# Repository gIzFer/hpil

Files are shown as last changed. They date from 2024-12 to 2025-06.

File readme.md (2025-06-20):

# HP-IL bridge/translator to USB/Serial

## What does it do
So what does this do? The device simply takes what it receives from the HP-IL side and sends it over serial. Same in the other direction. sends 2 bytes, the `command` and the `data` terminated with a `'\n'` (ascii 10) character

## Why
I had a 3468A and wanted to control it from my computer and make the electronics circuit simple an easy and of parts everyone could have at hand. Difficulty was relayed onto the firmware, but even so was kept simple without implementing the state machines of the protocol.

## Materials needed
- Atmega328p
- 2 NPN and 4 PNP transistors. 2 PNP handle the input and the other 2 and 2 are for a push pull arrangement to send data. I sprinkled on them some diodes to speed them up.
- Ethernet transformer. Fastest pulses are around 1µs and an ethernet transformer seems to be able to handle that quite well. You can find them in every device having a rj45 port, old computers, routers, switches, etc.

[client docs](./client/readme.md)

## Added made up codes

### 1XX

They are for extra messages you can send to the device, like asking it to just send the message it just received

#### 1XX List of codes
- 101: send back the last message received
- 102: get calibration data
- 103: get firmware version

### 2XX

They are for extra messages you can receive from the device  like errors

#### 2XX List of codes
- 201: received message buffer overflowed, answers with 201 and the last byte it received

# todo:
- read pins instead of delays (NOPs) when talking to be able to read answer at the same time im writing
- add images to readme
- add "console mode" so no need for the python client, to be able to directly send the commands to it

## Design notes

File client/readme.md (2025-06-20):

# HP3468A client

Example on how to interact with the firmware. I made it to mainly use it with the HP3468A. No idea of how it will interact with any other HP-IL device.

----
##### Contents
- [How to use](#How-to-use)
- [Code "docs"](#Code-"docs)
 - [setDisplay](#setDisplay)
 - [setDigits](#setDigits)
 - [setTriggerMode](#setTriggerMode)
 - [setAutoZero](#setAutoZero)
 - [setFunction](#setFunction)
 - [readSingleValue](#readSingleValue)
 - [getStatus](#getStatus)
 - [printStatus](#printStatus)
 - [getCal](#getCal)
 - [printCal](#printCal)
 - [triggerReading](#triggerReading)

 ----
## How to use

`multimeter = HP3468A(args.usb_id)`
in my case I get it at /dev/ttyUSBn, so i.e. I call `./main.py --usb_id 0` to run the example

uhh... Not very multiOS compatible... change accordingly to your OS... :P
`self.ser = serial.Serial("/dev/ttyUSB" + str(usb_id), 115200, timeout=1)`

## Code "docs"

### setDisplay

**desc**: changes display mode to either normal or to show text

**method**: `setDisplay(displayMode_, text="")`

**params**:

-   `displayMode_`: enum `displayModes.normal` or `displayModes.text`
-   `text`: empty by default. automatically truncated if length exceeds available space on display

_always write text in uppercase characters otherwise cursed things might show_

_(they "stored other characters in the lowercase characters space")_

### setDigits

**desc**: changes meter digits. Precision and sampling speed change accordingly

**method**: `setDigits(digits)`

**params**:

-   `digits`: valid values are 3, 4 and 5

### setTriggerMode

**desc**: trigger internally or single trigger

**method**: `setTriggerMode(triggerMode_)`

**params**:

-   `triggerMode_`:  enum `triggerModes.internal` or `triggerModes.single`

### setAutoZero

**desc**: Enable or disable autozero, enabled by default. (Nulls internal offset errors)

**method**: `setAutoZero(value)`

**params**:

-   `value`:  True or False

### setFunction

**desc**: Configure function and its range

**method**: `setFunction(function_, range=0)`

**params**:

-   `function_`: enum `functions`
-   `range`: numerical value.

Since range depends on option parameters values are combined here:

-   `functions.DC_voltage`: 0 (Autorange), 1 (.3V), 2 (3V), 3 (30V), 4 (300V)
-   `functions.AC_voltage`: 0 (Autorange), 1 (.3V), 2 (3V), 3 (30V), 4 (300V)
-   `functions.ohms_2_wire`: 0 (Autorange), 1 (300Ω), 2 (3KΩ), 3 (30KΩ), 4 (300KΩ), 5 (3MΩ), 6 (30MΩ)
-   `functions.ohms_4_wire`: 0 (Autorange), 1 (300Ω), 2 (3KΩ), 3 (30KΩ), 4 (300KΩ), 5 (3MΩ), 6 (30MΩ)
-   `functions.DC_current`: 0 (Autorange), 1 (3A)
-   `functions.AC_current`: 0 (Autorange), 1 (3A)
-   `functions.ohms_extended`: 0 (Autorange), 1 (10MΩ//Rx)

### readSingleValue

**desc**: read currently measured value

**method**: `readSingleValue()`

**params**: none, returns float

### getStatus

**desc**: probes the meter for the status bytes (unsure if it works correctly, need to do more research and testing on this)

**method**: `getStatus()`

**params**: none, returns nothing, use [`printStatus()`](#printStatus) to get reply

### printStatus

**desc**: prints response to `getStatus()`

**method**: `printStatus():`

**params**: none, simply prints data gotten by [`getStatus()`](#getStatus)

### getCal

**desc**: gets the meter's raw cal data

**method**: `getCal()`

**params**: none, returns nothing, use [`printCal()`](#printCal) to get the processed calibration data

### printCal

**desc**: prints response to [`getCal()`](#getCal). Meter stores pairs of offset and gain per range in DCV and OHMS. ACV and current stores only one pair each. (List of ranges with calibration pairs: `DC_0V3`, `DC_3V`, `DC_30V`, `DC_300V`, `AC_V`, `R_300`, `R_3k`, `R_30k`, `R_300k`, `R_3M`, `R_30M`, `I_3A`)

Sources: [HP Journal Issue Feb 1982 (volume 34)](https://archive.org/details/Hewlett-Packard_Journal_Vol._34_No._2_1983-02_Hewlett-Packard/page/n11/mode/2up) & [HP Museum thread "3421A CAL RAM"](https://www.hpmuseum.org/forum/thread-8061-page-2.html) | [Archived](https://web.archive.org/web/20240920172540/https://hpmuseum.org/forum/thread-8061-page-2.html)

**method**: `printCal()`

**params**: none, simply prints the cal data gotten by [`getCal()`](#getCal)

### triggerReading

**desc**: triggers a reading

**method**: `triggerReading():`

**params**: none, simply triggers a reading, use [`readSingleValue()`](#readSingleValue) to get readen value

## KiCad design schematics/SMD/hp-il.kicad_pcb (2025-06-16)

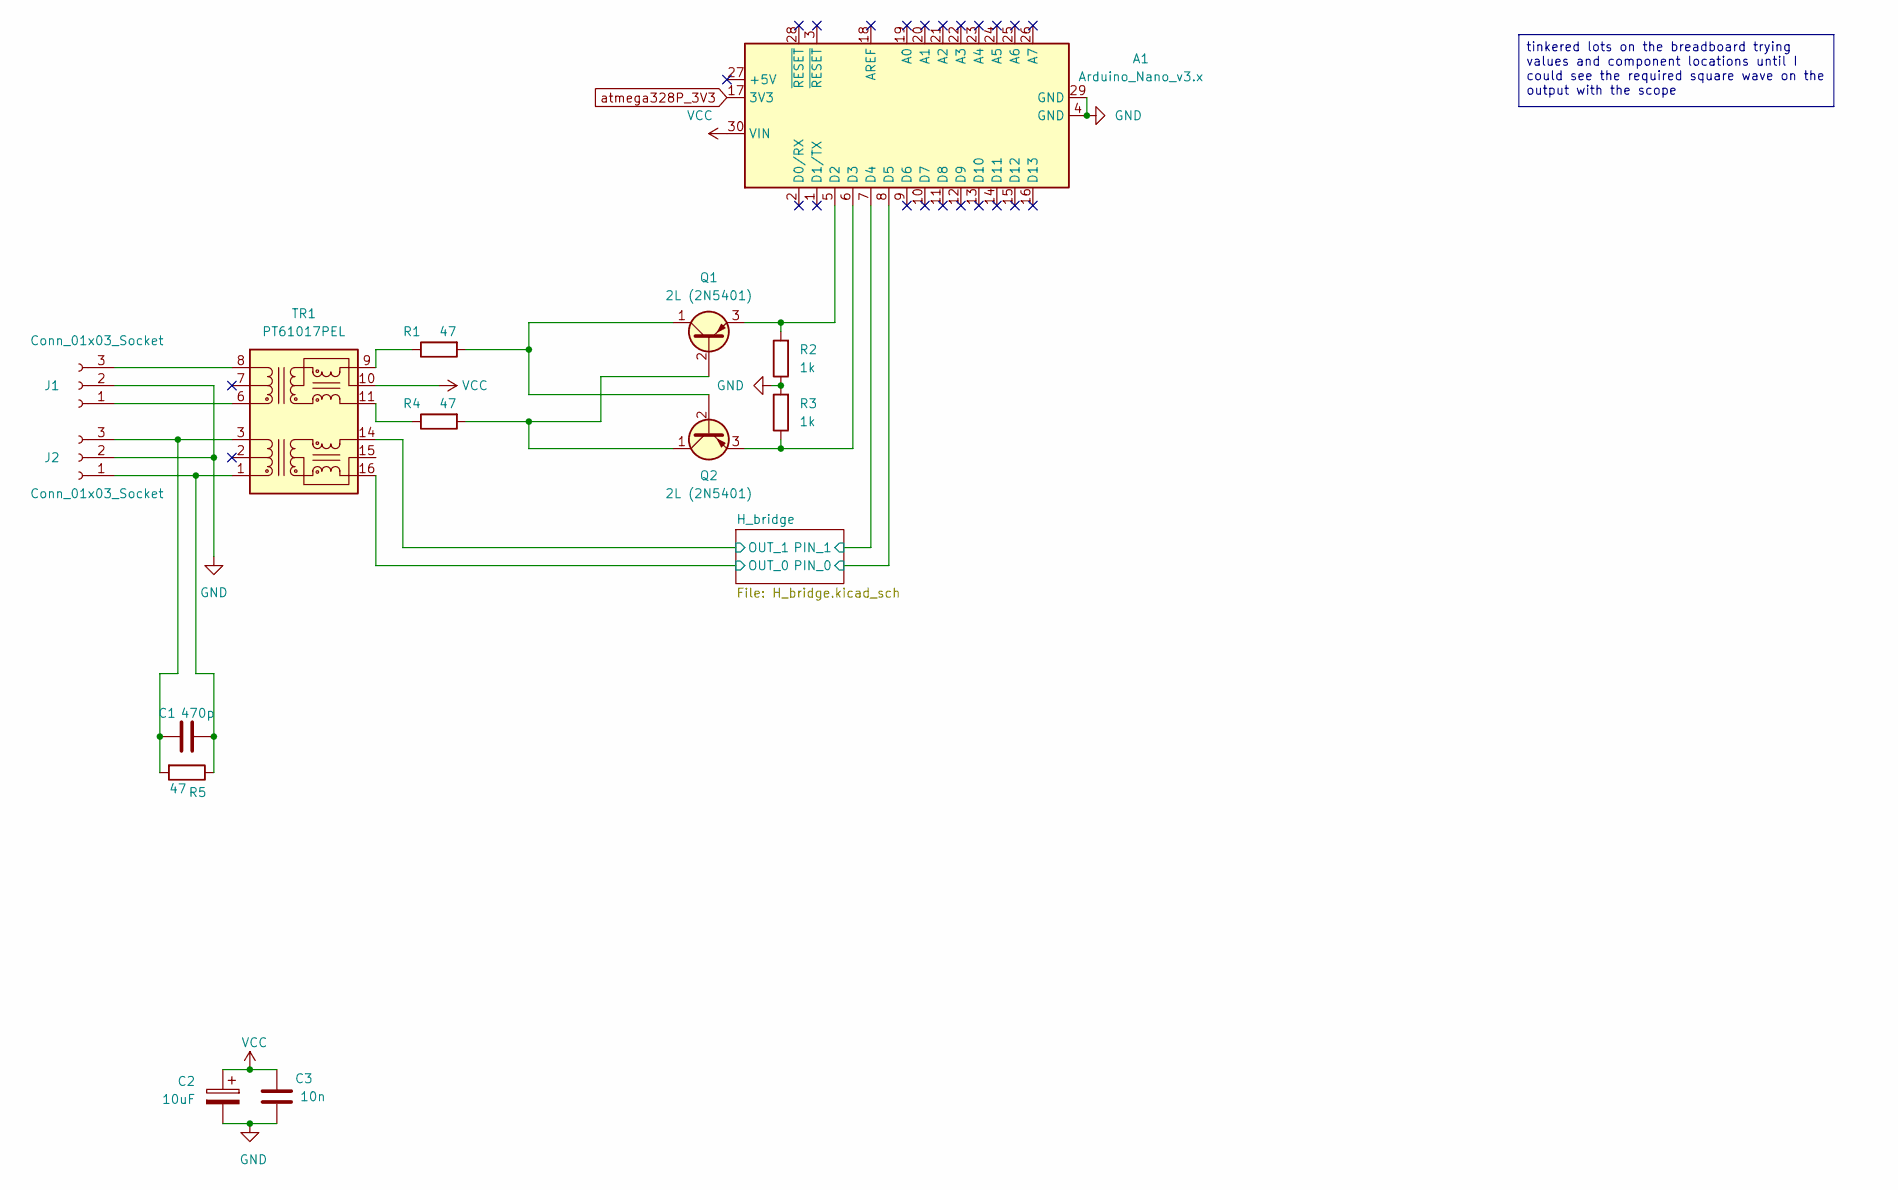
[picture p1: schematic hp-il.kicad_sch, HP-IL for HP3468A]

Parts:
A1: Arduino_Nano_v3.x; Arduino_Nano
C1: 470p; C_0603_1608Metric_Pad1.08x0.95mm_HandSolder
C2: 10uF; CP_Radial_D4.0mm_P2.00mm
C3: 10n; C_0603_1608Metric_Pad1.08x0.95mm_HandSolder
J1, J2: Conn_01x03_Socket; PinHeader_1x03_P2.54mm_Vertical
Q1, Q2: 2L (2N5401); SOT-23_Handsoldering_(5401_2L)
R1, R4, R5: 47; R_0603_1608Metric_Pad0.98x0.95mm_HandSolder
R2, R3: 1k; R_0603_1608Metric_Pad0.98x0.95mm_HandSolder
TR1: PT61017PEL; Transformer_Ethernet_Bourns_PT61017PEL

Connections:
/H_bridge/OUT_0: TR1.16 (TX+); also elsewhere on the board
/H_bridge/OUT_1: TR1.14 (TX-); also elsewhere on the board
/H_bridge/PIN_0: A1.8 (D5); also elsewhere on the board
/H_bridge/PIN_1: A1.7 (D4); also elsewhere on the board
GND: A1.4 (GND), A1.29 (GND), C2.2, C3.2, J1.2, J2.2, R2.1, R3.2; also elsewhere on the board
unnamed: A1.5 (D2), Q1.3 (E), R2.2
unnamed: A1.6 (D3), Q2.3 (E), R3.1
unnamed: J1.1, TR1.6 (RD+)
unnamed: J1.3, TR1.8 (RD-)
unnamed: C1.2, J2.1, R5.1, TR1.1 (TD+)
unnamed: C1.1, J2.3, R5.2, TR1.3 (TD-)
unnamed: Q1.2 (B), Q2.1 (C), R4.2
unnamed: Q1.1 (C), Q2.2 (B), R1.2
unnamed: R4.1, TR1.11 (RX+)
unnamed: R1.1, TR1.9 (RX-)
VCC: A1.30 (VIN), C2.1, C3.1, TR1.10 (C_RX)
atmega328P_3V3: A1.17 (3V3); also elsewhere on the board

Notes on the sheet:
tinkered lots on the breadboard trying values and component locations until I could see the required square wave on the output with the scope

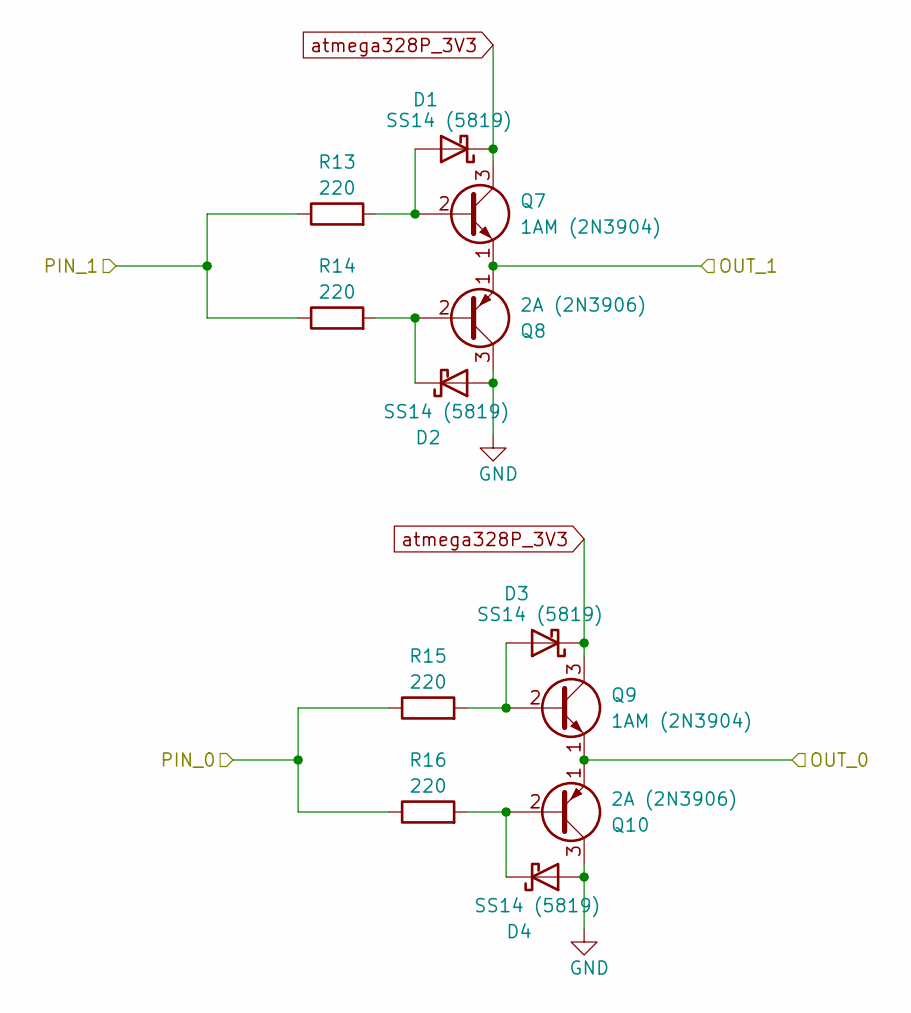
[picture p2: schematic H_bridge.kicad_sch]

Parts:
D1, D2, D3, D4: SS14 (5819); D_SMA_Handsoldering
Q7, Q9: 1AM (2N3904); SOT-23_Handsoldering_(3904_1AM)(3906_2A)
Q8, Q10: 2A (2N3906); SOT-23_Handsoldering_(3904_1AM)(3906_2A)
R13, R14, R15, R16: 220; R_0603_1608Metric_Pad0.98x0.95mm_HandSolder

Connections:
/H_bridge/OUT_0: Q9.1 (E), Q10.1 (E); also elsewhere on the board
/H_bridge/OUT_1: Q7.1 (E), Q8.1 (E); also elsewhere on the board
/H_bridge/PIN_0: R15.1, R16.1; also elsewhere on the board
/H_bridge/PIN_1: R13.1, R14.1; also elsewhere on the board
GND: D2.2 (A), D4.2 (A), Q8.3 (C), Q10.3 (C); also elsewhere on the board
unnamed: D1.2 (A), Q7.2 (B), R13.2
unnamed: D2.1 (K), Q8.2 (B), R14.2
unnamed: D3.2 (A), Q9.2 (B), R15.2
unnamed: D4.1 (K), Q10.2 (B), R16.2
atmega328P_3V3: D1.1 (K), D3.1 (K), Q7.3 (C), Q9.3 (C); also elsewhere on the board

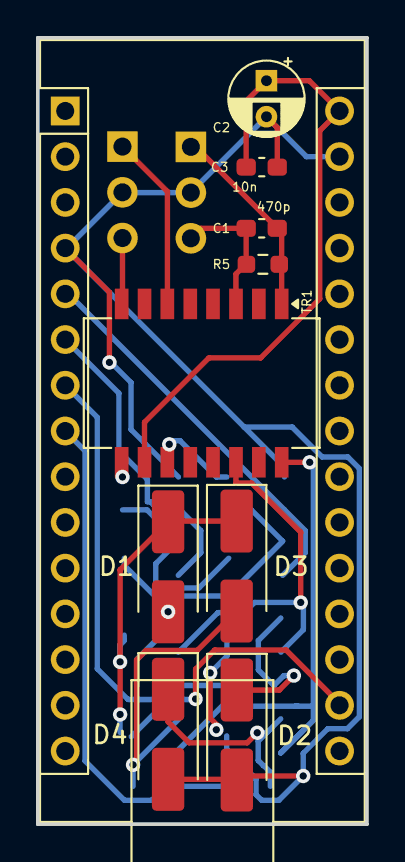
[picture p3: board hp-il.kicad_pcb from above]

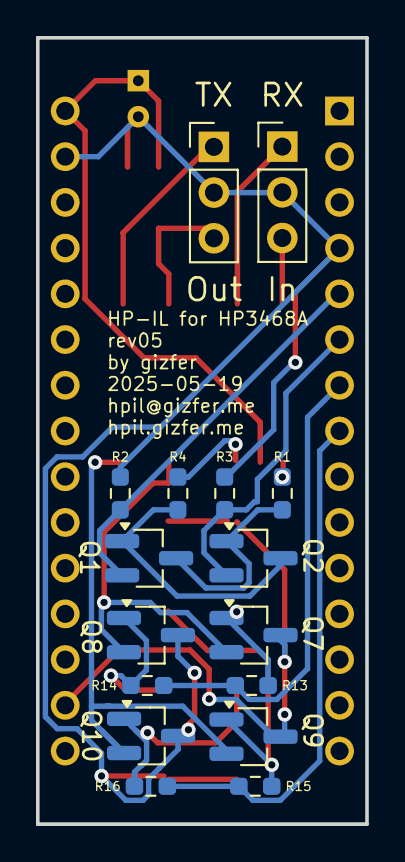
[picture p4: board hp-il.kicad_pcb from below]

Board: 2 copper layers, 18.3 x 43.7 mm, 26 parts (16 on the bottom side), 21 nets.

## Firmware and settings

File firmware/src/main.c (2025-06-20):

//configs
#define F_CPU 16000000UL

#define BAUDRATE 115200

#define VERBOSE
#define DEBUG_PIN


#include <util/delay.h>
#include <avr/io.h>
#include <stdint.h>
#include <stdio.h>
#include <avr/interrupt.h>
#include <string.h>


#include "interrupts.h"
#include "uart.h"
#include "decoder.h"
#include "talker.h"
#include "hpil.h"
#include "version.h"

#ifdef DEBUG_PIN
	#define LED PORTB4 //pin 12 for debugging
#endif

int main(void) {
#ifdef DEBUG_PIN
	DDRB |= (1 << LED); // set pin 12 as out
#endif
	setupUart(F_CPU, BAUDRATE);

	setupTalker();

	setupInterrupts();

	sendStr(VERSION);
	sendStr("\nready\n");
	for(;;) {
		if((PIND & 0b1100)){//if any of the input pins read a high
			sample();
			decodeFrame(true);
		}
		if(uart_commandParsed == false) //needed as the time to go into the function is too much
		hpil_handle();
	}
}

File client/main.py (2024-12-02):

#!/usr/bin/python3
import argparse
import time

from hpil_3468A import HP3468A

parser = argparse.ArgumentParser(description='HP-IL Client')
parser.add_argument('--usb_id', required=True, metavar='usb#', type=int, help='USB_ID - `ls /dev/ttyUSB*`')
args = parser.parse_args()

print("start")
multimeter = HP3468A(args.usb_id)

multimeter.setDisplay(multimeter.displayModes.text,  "HELLO WORLD")

print("end")

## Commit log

2024-12-02 minor rework, added comments
    [hpil.c, main.c, uart.c]
2024-12-02 added schematic and client
2024-12-02 renamed schematic folder and cleaned files
    [H_bridge.kicad_sch, RS-485.kicad_sch, hp-il.kicad_pcb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]
2024-12-02 added .gitignore to schematics
2025-06-16 created compact SMD version, kept THT one
    [H_bridge.kicad_sch, RS-485.kicad_sch, hp-il.kicad_pcb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]
